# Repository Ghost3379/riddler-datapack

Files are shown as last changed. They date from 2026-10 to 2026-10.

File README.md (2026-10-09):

# Enigma Data Pack - Robin: Origins

A functional custom electronic prop for the indie fan film *"Robin: Origins"*. The design is based on the iconic Enigma Data Packs from the Batman *Arkham* universe, engineered as an interactive gadget that can be carried on set and connected to a PC via USB-C to mount as an encrypted data drive.

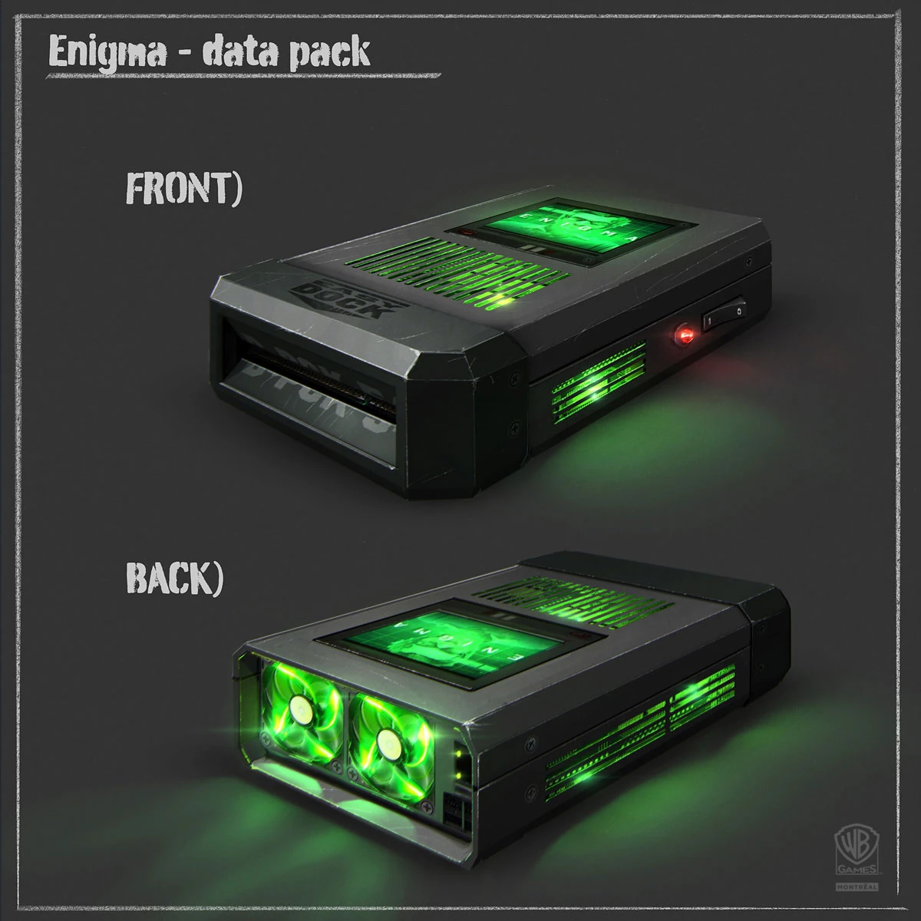
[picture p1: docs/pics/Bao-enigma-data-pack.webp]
Enigma Data Pack Concept


---

## Hardware Versions

The project contains two distinct hardware designs:

1. **Mini Version (Movie Prop - In Production):** An ultra-compact, stunt-safe, pocket-sized tactical drive (~85 × 57 × 12 mm, inspired by rugged portable SSDs like the Samsung T7 Shield). Tailored specifically for the film's action scenes and PC terminal connection.
2. **Full-Size Replica Version:** A heavy, 1:1 scale Arkham military cartridge featuring dual active 40mm cooling fans, internal LiPo battery charging, and full power-rail boost converters.

---

### 1. Mini Version (Movie Hero Prop)
> Located in: [`PCB/Mini Version/Riddler-Datapack mini/`](PCB/Mini%20Version/Riddler-Datapack%20mini/)

Optimized for durability, pocket portability during physical stunt chases, and reliable on-set PC docking:

* **Form Factor:** Compact 60 × 45 mm PCB inside an ~85 × 57 mm enclosure with chamfered `PCIe NVMe` nose cone and front grille vents.
* **Microcontroller:** ESP32-S3-MINI-1 (dual-core, native USB OTG, onboard PCB antenna).
* **Power Architecture:** Purely bus-powered via USB-C (5V VBUS). High-efficiency TLV62568 synchronous step-down buck converter supplies 3.3V @ up to 1A. No internal LiPo batteries required on set, eliminating safety risks and battery downtime.
* **Storage:** MicroSD card socket wired via high-speed **4-bit SDMMC** with hardware pull-ups (4.7kΩ) for fast read/write speeds when mounted as a USB Mass Storage (MSC) drive.
* **Display:** 1.14" IPS TFT LCD (ST7789, 240×135) for crisp "ENIGMA" animations and boot terminals.
* **Illumination:** Integrated addressable RGB LEDs (WS2812B / SK6812) projecting the signature neon green glow through the front casing grille.
* **Protection:** Dedicated USBLC6-2P6 ESD protection on high-speed USB data lines and reverse-polarity Schottky diode on VBUS.

---

### 2. Full-Size Replica Version
> Located in: [`PCB/Riddler-Datapack/`](PCB/Riddler-Datapack/)  
> Full schematic export: [Riddler-Datapack_v0p5.pdf](docs/circuit%20diagrams/Riddler-Datapack_v0p5.pdf)

The full-scale desktop/showcase replica with complete internal subsystem autonomy:

* **Microcontroller:** ESP32-S3-WROOM-1U.
* **Active Cooling:** Dual 40x40mm cooling fans with independent PWM speed control.
* **Power Management:**
  * BQ25170DSGR standalone linear LiPo battery charger (chargeable via USB-C).
  * TPS61023 5V boost converter for fans and high-brightness LED arrays.
  * TLV62568DBV 3.3V buck regulator for MCU logic.
* **Level Shifting:** SN74AHCT125 / 74AHCT1G125 high-speed logic level shifting for 5V LED data lines.
* **Controls:** Physical rocker power switch (`1 / 0`) and dual fan headers.

---

## Visual Reference & In-Game Footage

| Front View (Idle / Off) | Front View (Active "ENIGMA" Display & LEDs) |
| :---: | :---: |
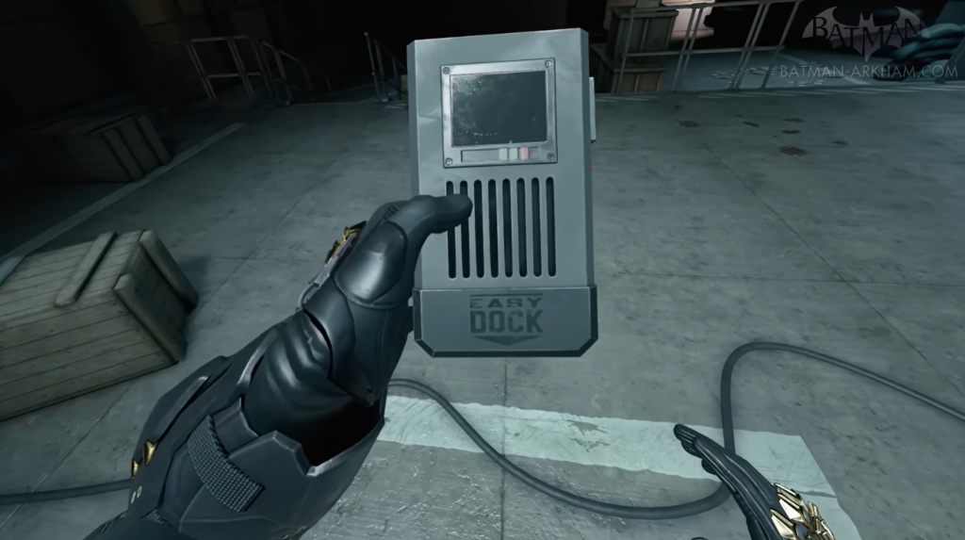
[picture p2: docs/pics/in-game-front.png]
Front View Idle
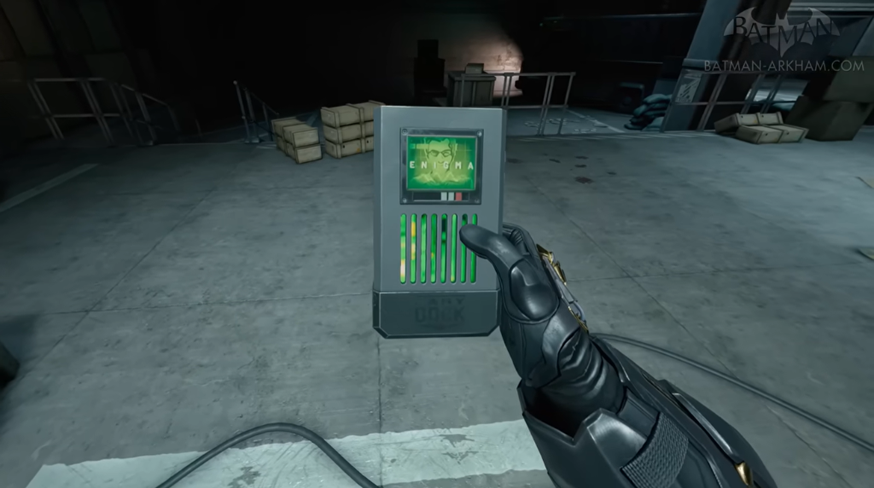
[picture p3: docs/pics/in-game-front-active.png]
Front View Active
|  |  |

| Top Fans & Lighting | Side Controls & Switch | Bottom Dock ("D-PCK 54") |
| :---: | :---: | :---: |
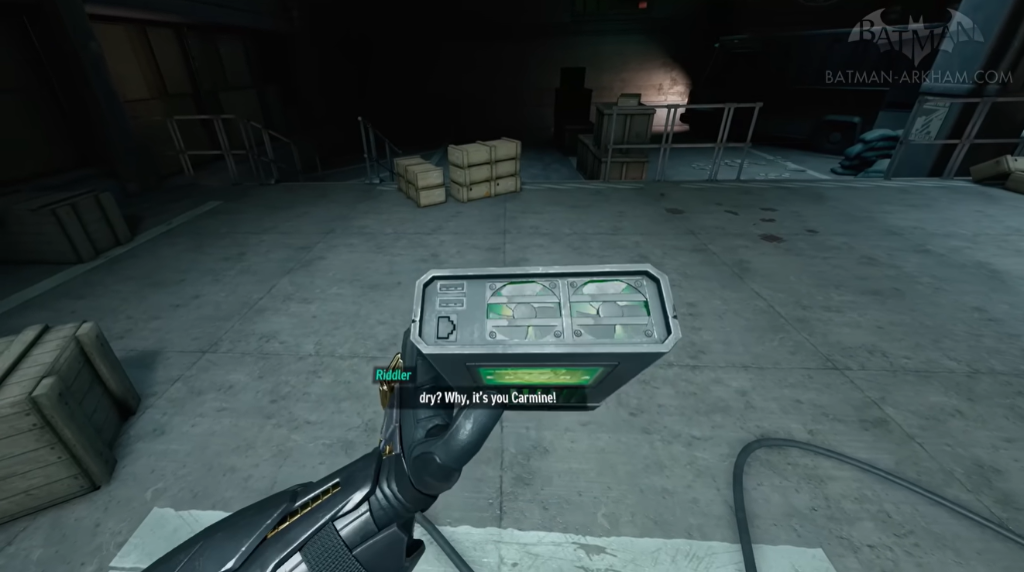
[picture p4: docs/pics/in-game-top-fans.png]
Top View
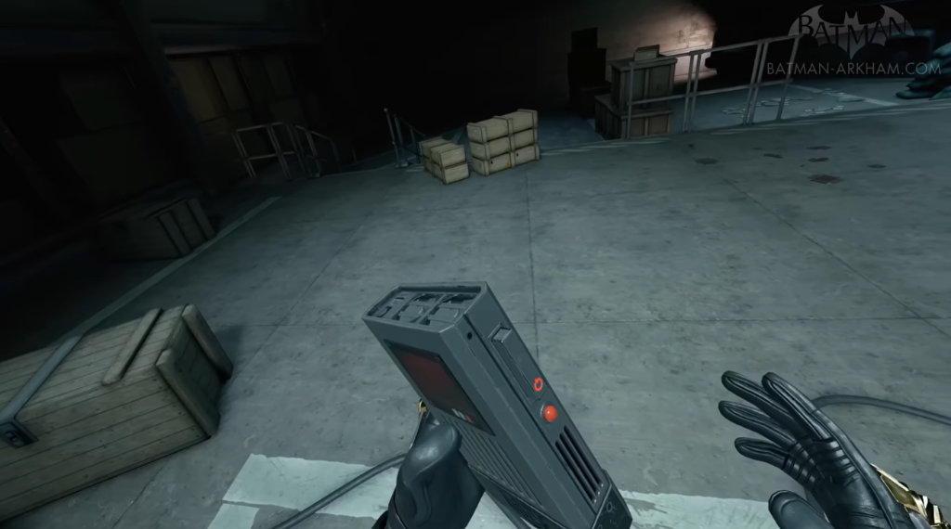
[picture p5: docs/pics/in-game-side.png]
Side View
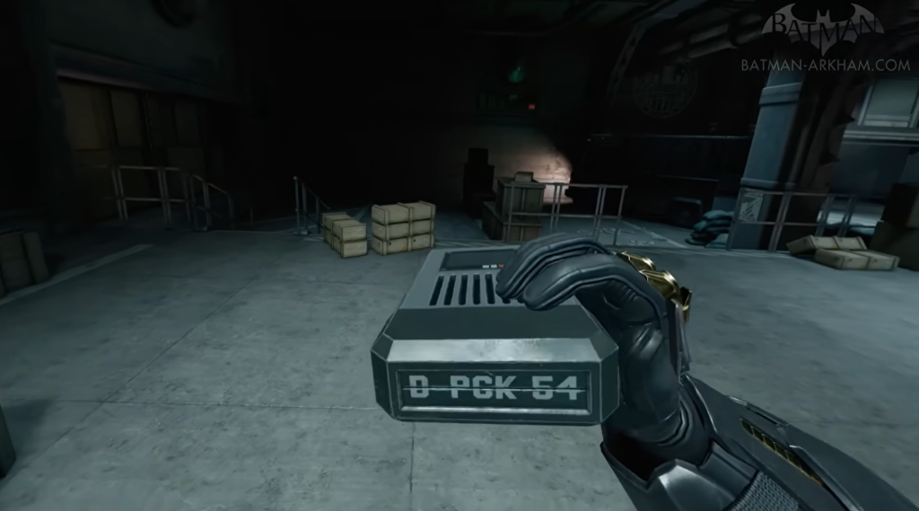
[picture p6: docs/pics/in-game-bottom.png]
Bottom View
|  |  |  |

---

## Sources & Credits

* **Concept Art:** [Arkham City Fandom - Enigma Datapack](https://arkhamcity.fandom.com/wiki/Enigma_Datapack?file=Bao-enigma-data-pack.jpg)
* **Video Game Screenshots & Footage:** [Batman Arkham - Enigma Datapacks Gameplay Footage (YouTube)](https://www.youtube.com/watch?v=1w_udK2QxwU)

---

## License
The software/firmware in the `Firmware` directory is licensed under the GNU General Public License v3.0 (GPLv3).

The hardware design files in the `PCB` directory are licensed under the CERN Open Hardware Licence Version 2 - Strongly Reciprocal (CERN-OHL-S).

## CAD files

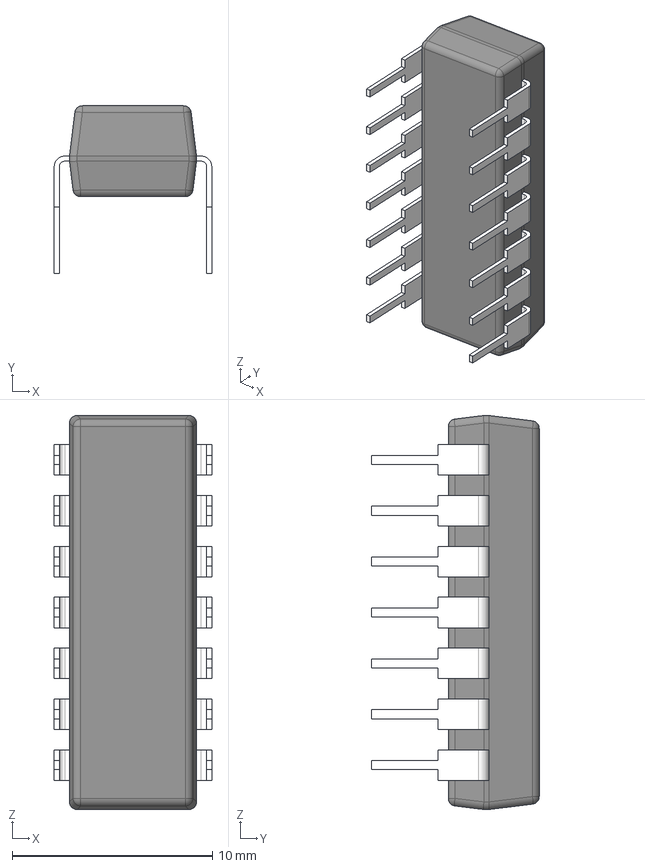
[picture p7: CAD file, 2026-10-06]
PCB/External Footprints&Symbols/3d/N0014A.stp
7.87 x 8.37 x 19.7 mm
BODY_N0014A_AF0
LEAD_N0014A_AF1
LEAD_N0014A x 10
LEAD_N0014A_AF3
LEAD_N0014A_AF0
LEAD_N0014A_AF2

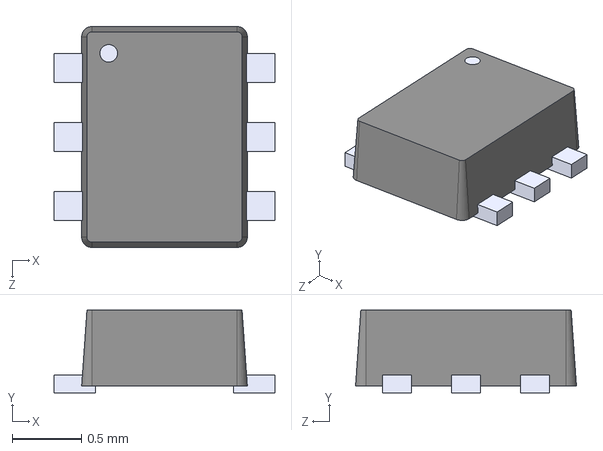
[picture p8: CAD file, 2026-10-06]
PCB/External Footprints&Symbols/3d/TPS61023DRLR.step
1.60 x 0.6 x 1.60 mm

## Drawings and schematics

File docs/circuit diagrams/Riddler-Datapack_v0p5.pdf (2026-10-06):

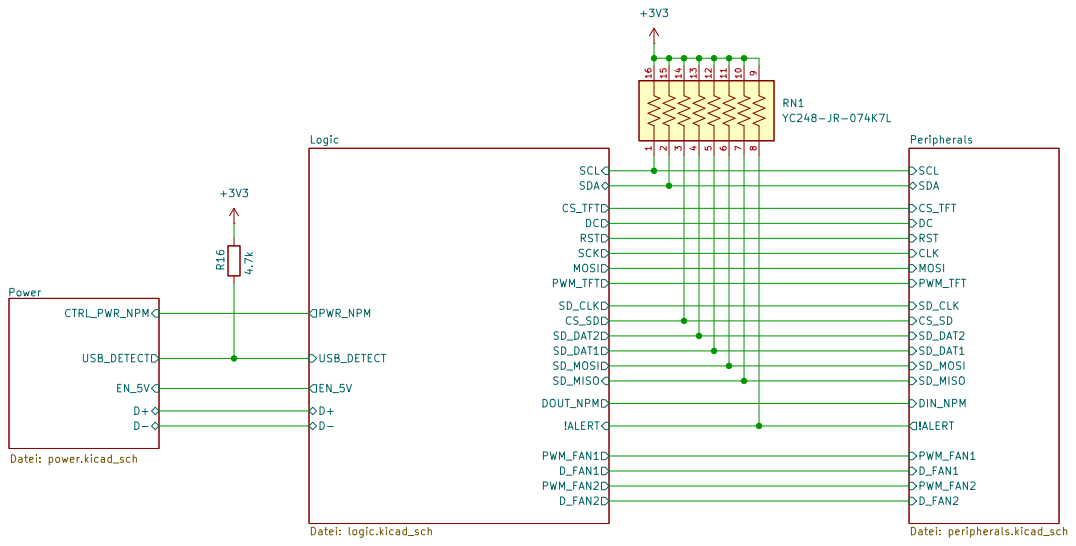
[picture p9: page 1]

D_FAN1 D_FAN2 MOSI PWM_FAN1 PWM_FAN2 PWM_TFT RST SCL SDA SD_DAT2
SD_DAT1 CLK

Size: A4 | Rev:
KiCad E.D.A. 10.0.5 | Id: 1/4

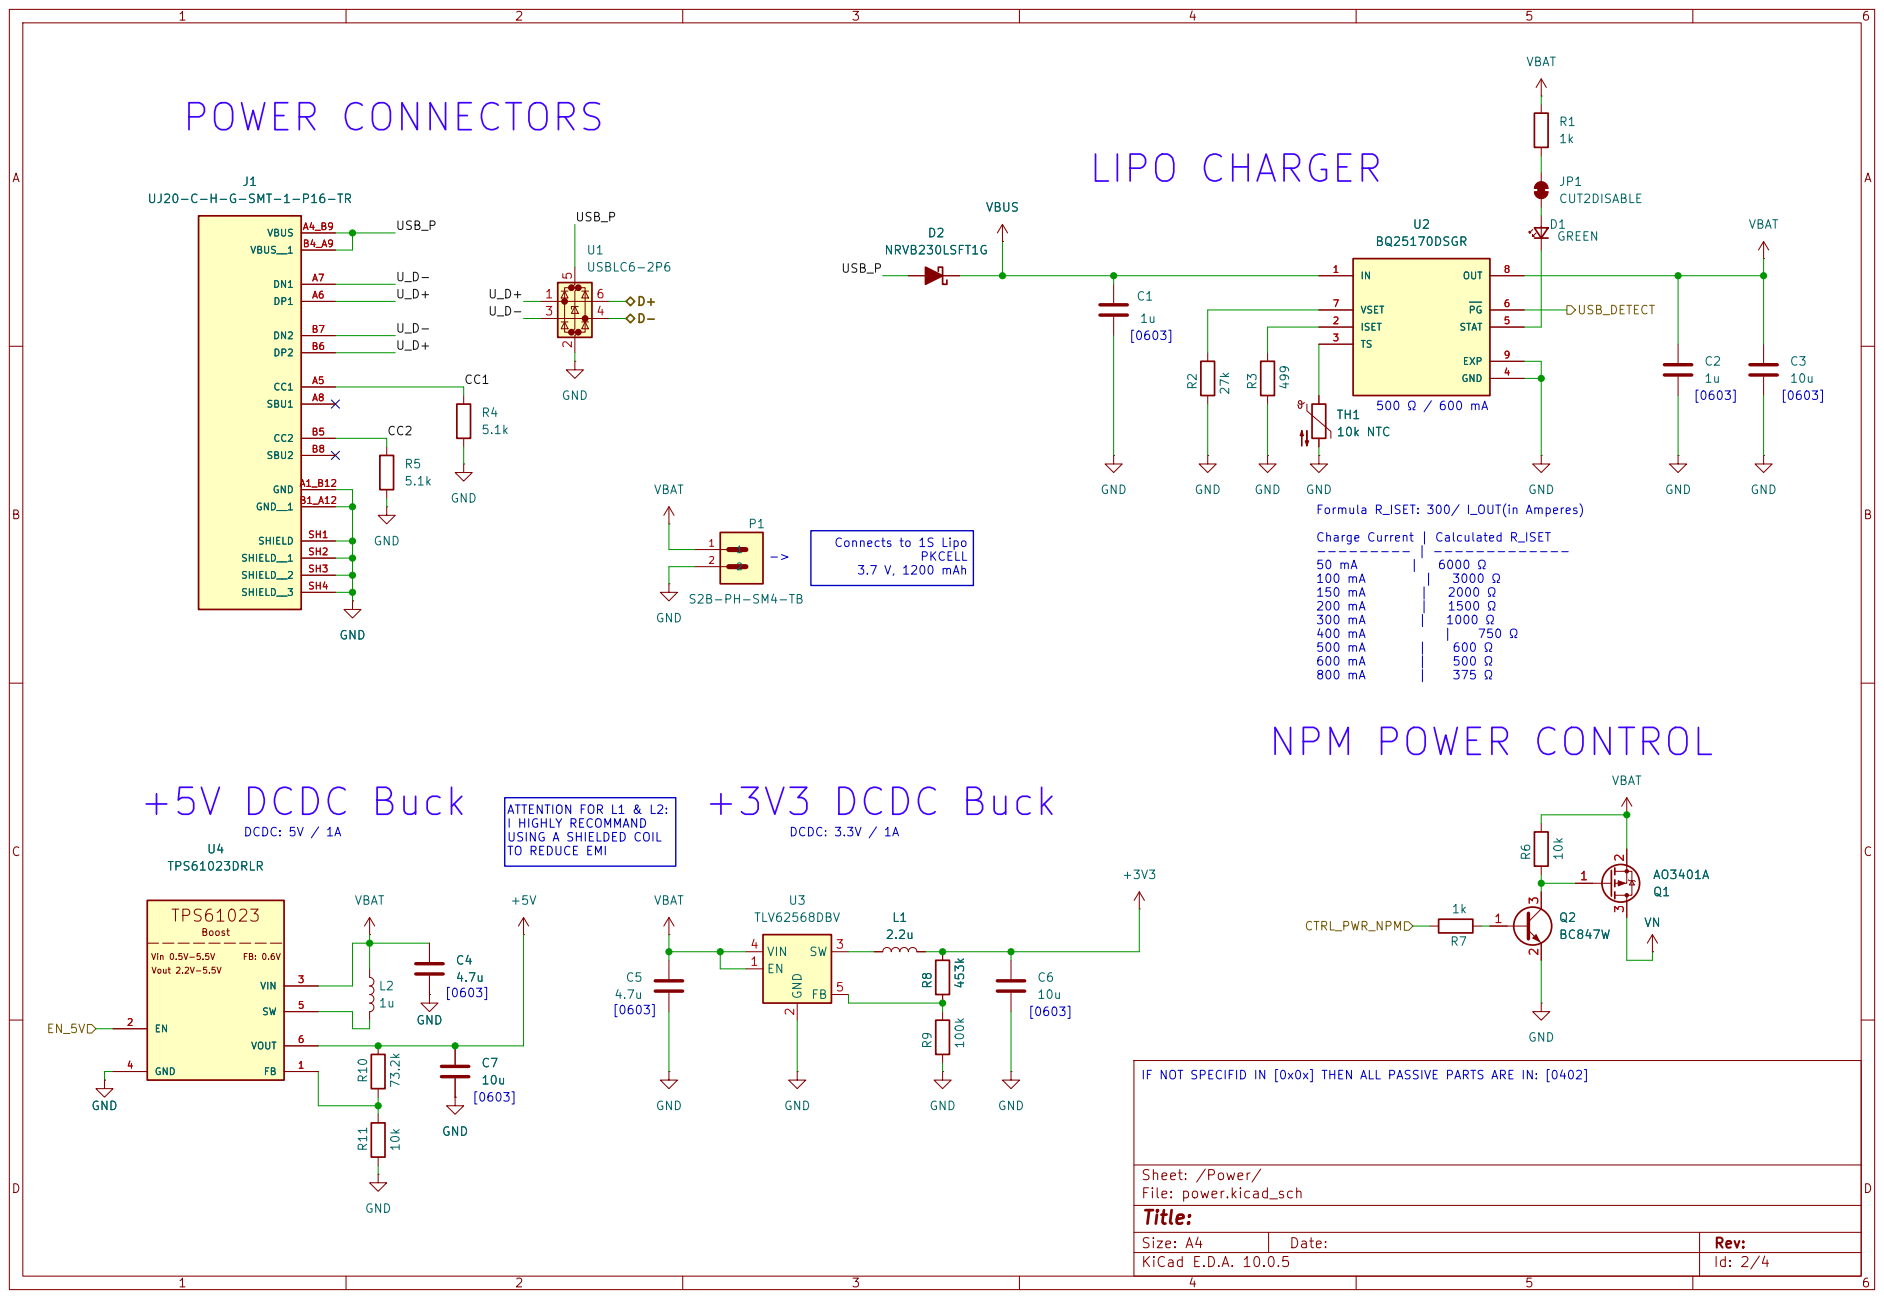
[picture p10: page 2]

ATTENTION FOR L1 & L2:
I HIGHLY RECOMMAND USING A SHIELDED COIL

IF NOT SPECIFID IN [0x0x] THEN ALL PASSIVE PARTS ARE IN: [0402]

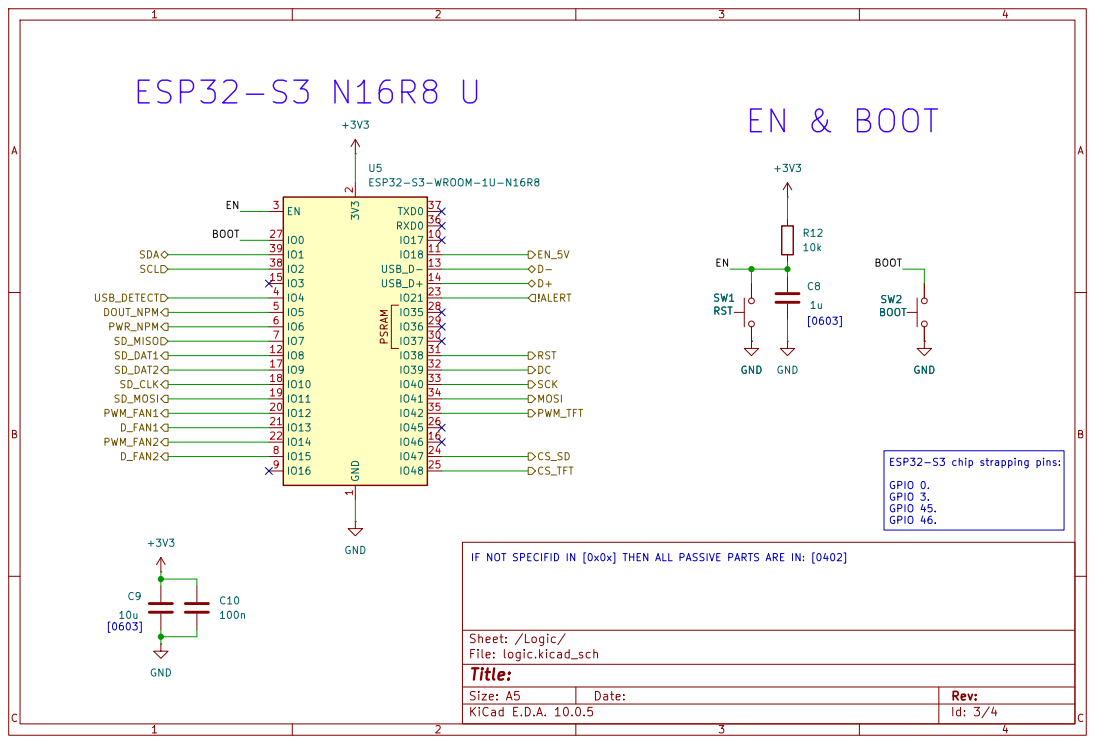
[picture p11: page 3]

[0603] ESP32-S3 chip strapping pins: GPIO 0. GPIO 3. GPIO 45. GPIO 46. SW2 BOOT GND

IF NOT SPECIFID IN [0x0x] THEN ALL PASSIVE PARTS ARE IN: [0402]

Size: A5 | Rev: | C Date:
KiCad E.D.A. 10.0.5 | Id: 3/4

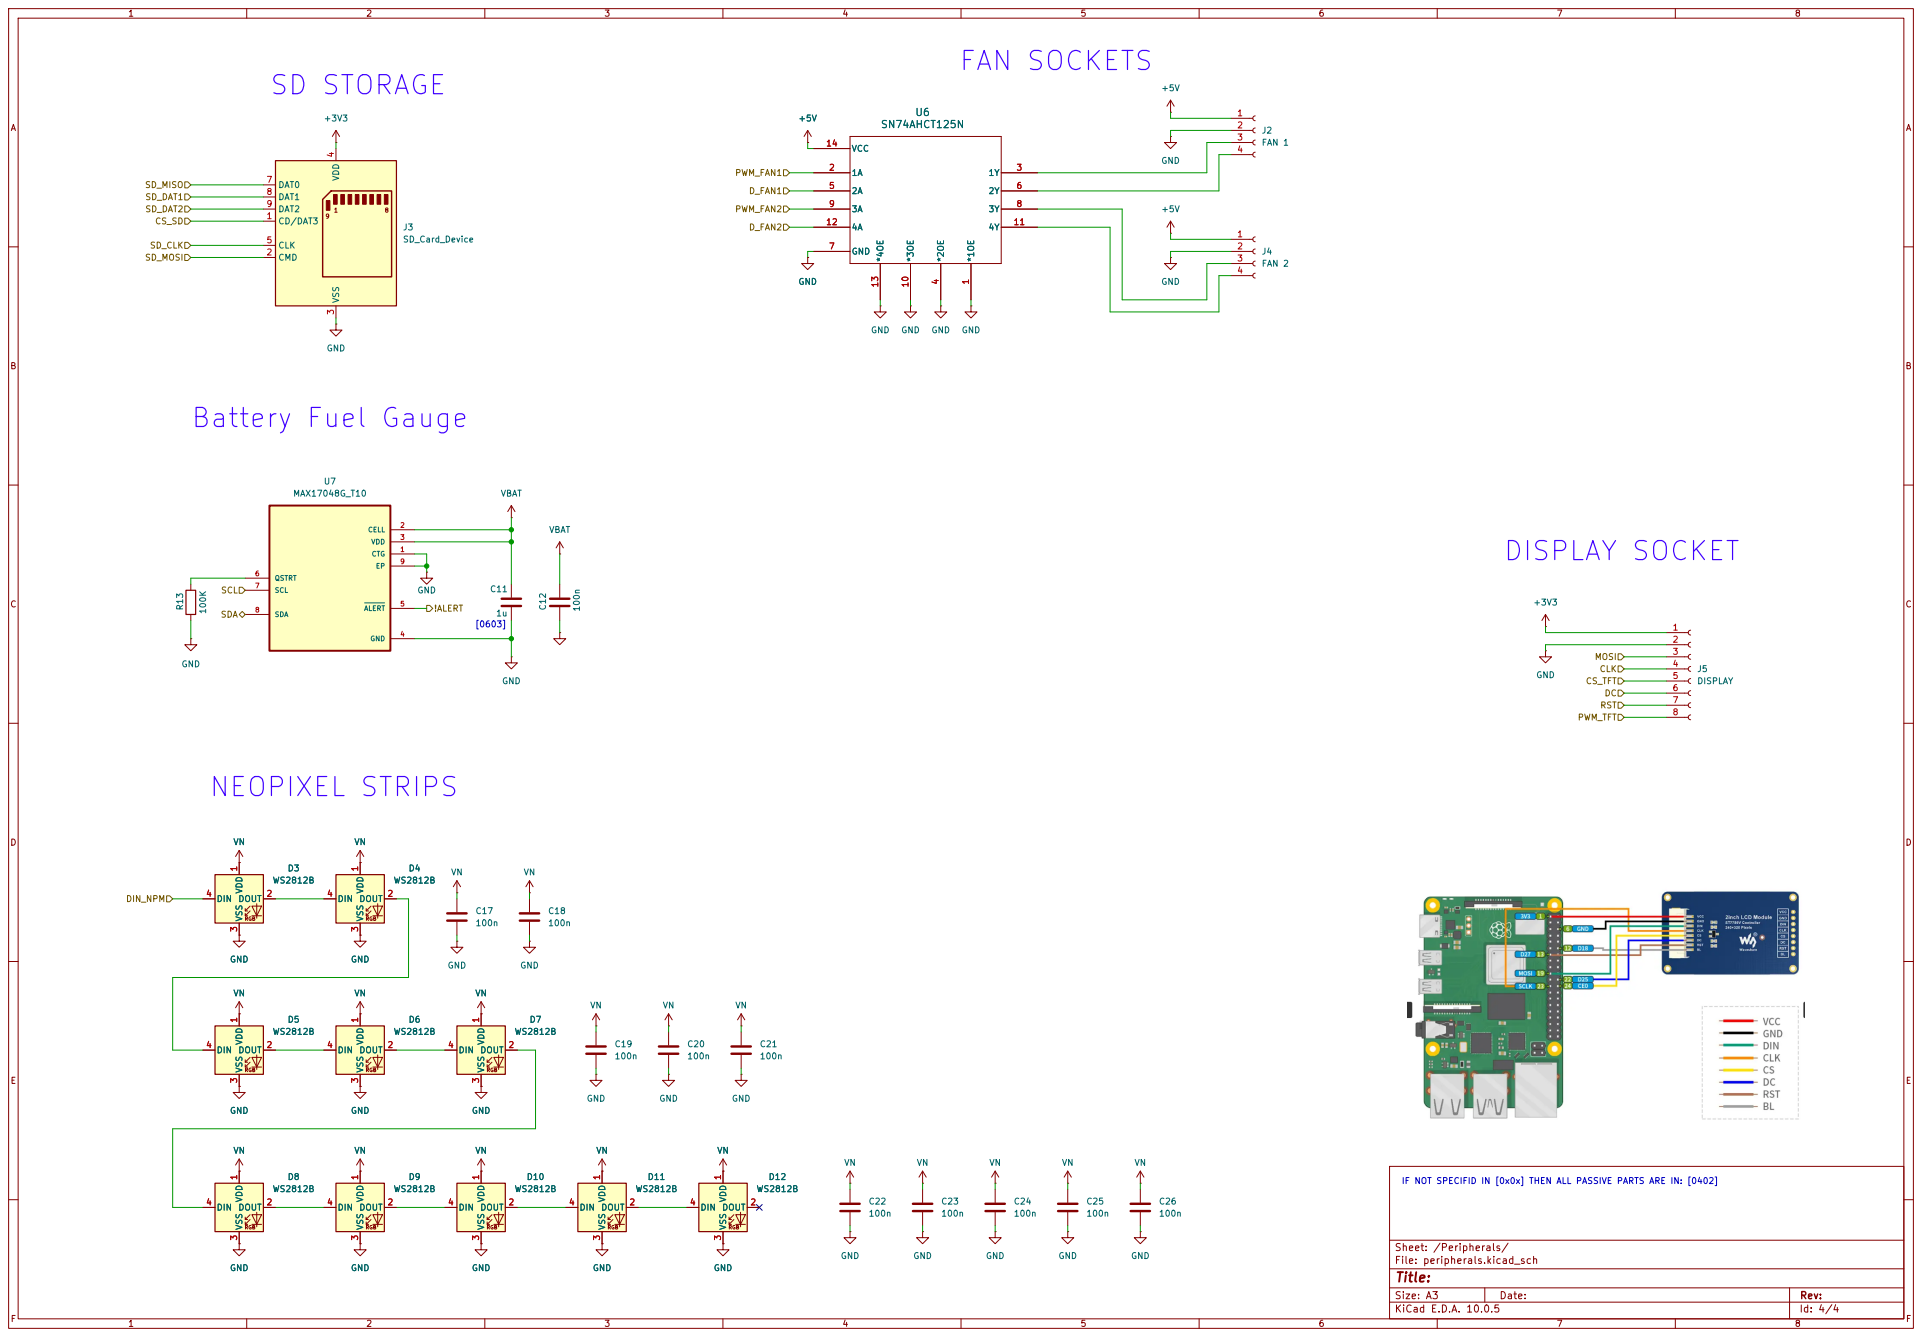
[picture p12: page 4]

IF NOT SPECIFID IN [0x0x] THEN ALL PASSIVE PARTS ARE IN: [0402]

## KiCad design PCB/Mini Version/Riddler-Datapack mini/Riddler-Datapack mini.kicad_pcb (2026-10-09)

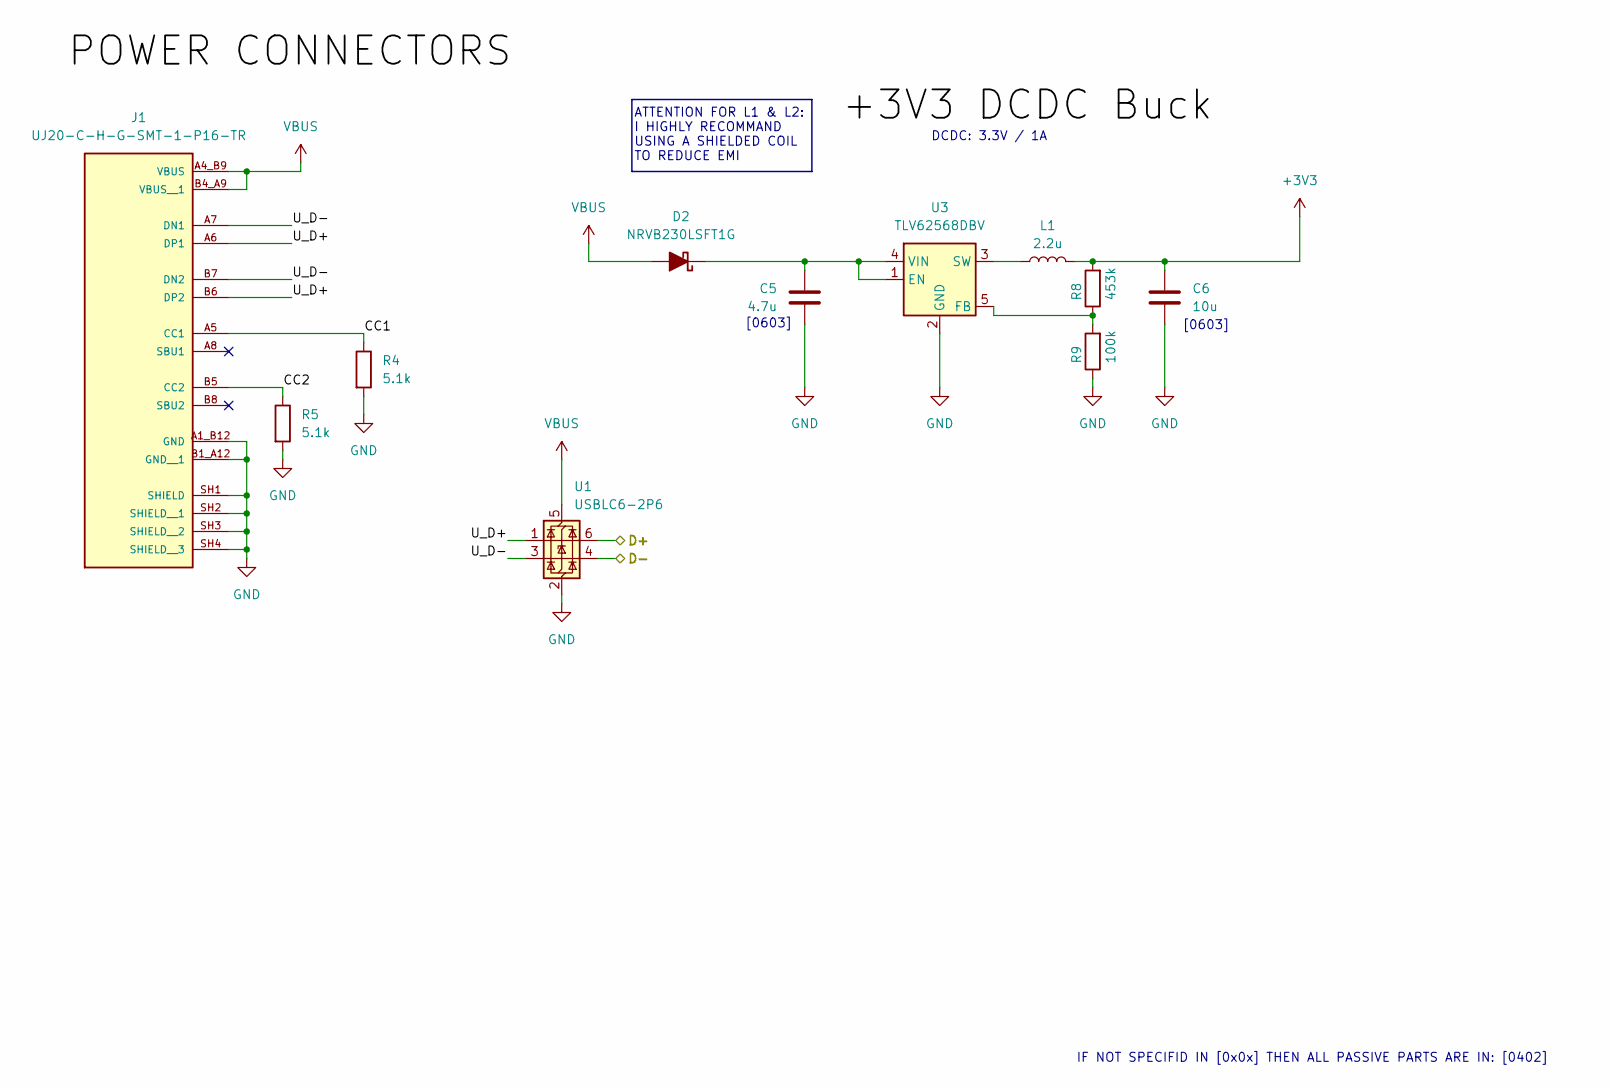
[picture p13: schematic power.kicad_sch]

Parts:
C5: 4.7u; C_0603_1608Metric
C6: 10u; C_0603_1608Metric
D2: NRVB230LSFT1G; D_SOD-123
J1: UJ20-C-H-G-SMT-1-P16-TR; SAMESKY_UJ20-C-H-G-SMT-1-P16-TR; PARTREV 1.0
L1: 2.2u; L_1008_2520Metric; Manufacturer part number SRN2510BTA-2R2M
R4, R5: 5.1k; R_0402_1005Metric
R8: 453k; R_0402_1005Metric
R9: 100k; R_0402_1005Metric
U1: USBLC6-2P6; SOT-666
U3: TLV62568DBV; SOT-23-5

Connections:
+3V3: C6.1, L1.2, R8.2; also elsewhere on the board
/Logic/D+: U1.6 (I/O1); also elsewhere on the board
/Logic/D-: U1.4 (I/O2); also elsewhere on the board
/Power/CC1: J1.A5 (CC1), R4.1
/Power/CC2: J1.B5 (CC2), R5.1
/Power/U_D+: J1.A6 (DP1), J1.B6 (DP2), U1.1 (I/O1)
/Power/U_D-: J1.A7 (DN1), J1.B7 (DN2), U1.3 (I/O2)
GND: C5.2, C6.2, J1.A1_B12 (GND), J1.B1_A12 (GND__1), J1.SH1 (SHIELD), J1.SH2 (SHIELD__1), J1.SH3 (SHIELD__2), J1.SH4 (SHIELD__3), R4.2, R5.2, R9.1, U1.2 (GND), U3.2 (GND); also elsewhere on the board
unnamed: C5.1, D2.1 (K), U3.1 (EN), U3.4 (VIN)
unnamed: R8.1, R9.2, U3.5 (FB)
unnamed: L1.1, U3.3 (SW)
VBUS: D2.2 (A), J1.A4_B9 (VBUS), J1.B4_A9 (VBUS__1), U1.5 (VBUS); also elsewhere on the board

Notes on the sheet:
[0603]
ATTENTION FOR L1 & L2: I HIGHLY RECOMMAND USING A SHIELDED COIL TO REDUCE EMI
DCDC: 3.3V / 1A
IF NOT SPECIFID IN [0x0x] THEN ALL PASSIVE PARTS ARE IN: [0402]

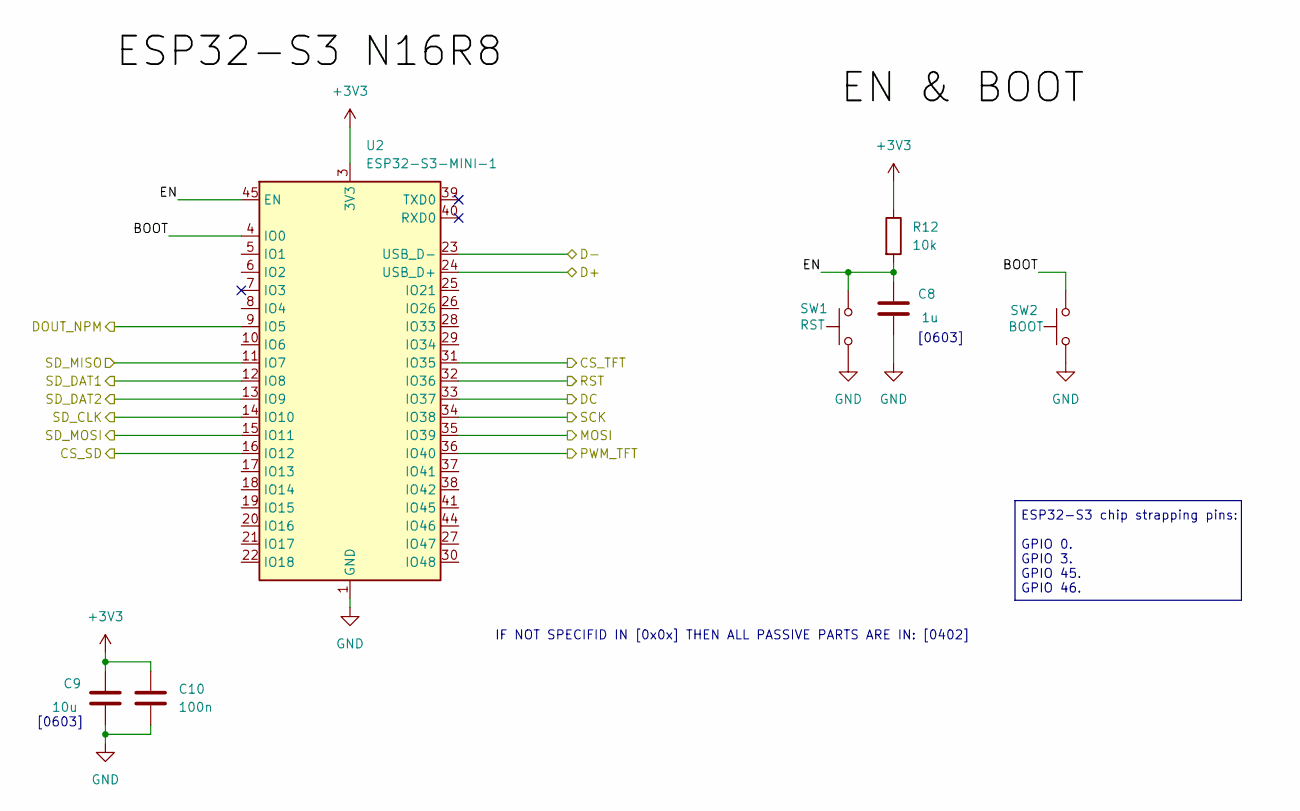
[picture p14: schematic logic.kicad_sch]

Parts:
C8: 1u; C_0603_1608Metric
C9: 10u; C_0603_1608Metric
C10: 100n; C_0402_1005Metric
R12: 10k; R_0402_1005Metric
SW1: RST; SW_Push_1P1T_NO_CK_KMR2
SW2: BOOT; SW_Push_1P1T_NO_CK_KMR2
U2: ESP32-S3-MINI-1; ESP32-S2-MINI-1

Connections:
+3V3: C9.1, C10.1, R12.1, U2.3 (3V3); also elsewhere on the board
/Logic/BOOT: SW2.2, U2.4 (IO0)
/Logic/CS_SD: U2.16 (IO12); also elsewhere on the board
/Logic/CS_TFT: U2.31 (IO35); also elsewhere on the board
/Logic/D+: U2.24 (USB_D+); also elsewhere on the board
/Logic/D-: U2.23 (USB_D-); also elsewhere on the board
/Logic/DC: U2.33 (IO37); also elsewhere on the board
/Logic/DOUT_NPM: U2.9 (IO5); also elsewhere on the board
/Logic/EN: C8.1, R12.2, SW1.2, U2.45 (EN)
/Logic/MOSI: U2.35 (IO39); also elsewhere on the board
/Logic/PWM_TFT: U2.36 (IO40); also elsewhere on the board
/Logic/RST: U2.32 (IO36); also elsewhere on the board
/Logic/SCK: U2.34 (IO38); also elsewhere on the board
/Logic/SD_CLK: U2.14 (IO10); also elsewhere on the board
/Logic/SD_DAT1: U2.12 (IO8); also elsewhere on the board
/Logic/SD_DAT2: U2.13 (IO9); also elsewhere on the board
/Logic/SD_MISO: U2.11 (IO7); also elsewhere on the board
/Logic/SD_MOSI: U2.15 (IO11); also elsewhere on the board
GND: C8.2, C9.2, C10.2, SW1.1, SW2.1, U2.1 (GND), U2.2 (GND), U2.42 (GND), U2.43 (GND), U2.46 (GND), U2.47 (GND), U2.48 (GND), U2.49 (GND), U2.50 (GND), U2.51 (GND), U2.52 (GND), U2.53 (GND), U2.54 (GND), U2.55 (GND), U2.56 (GND), U2.57 (GND), U2.58 (GND), U2.59 (GND), U2.60 (GND), U2.61 (GND), U2.62 (GND), U2.63 (GND), U2.64 (GND), U2.65 (GND); also elsewhere on the board

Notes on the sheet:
IF NOT SPECIFID IN [0x0x] THEN ALL PASSIVE PARTS ARE IN: [0402]
ESP32-S3 chip strapping pins: GPIO 0. GPIO 3. GPIO 45. GPIO 46.
[0603]

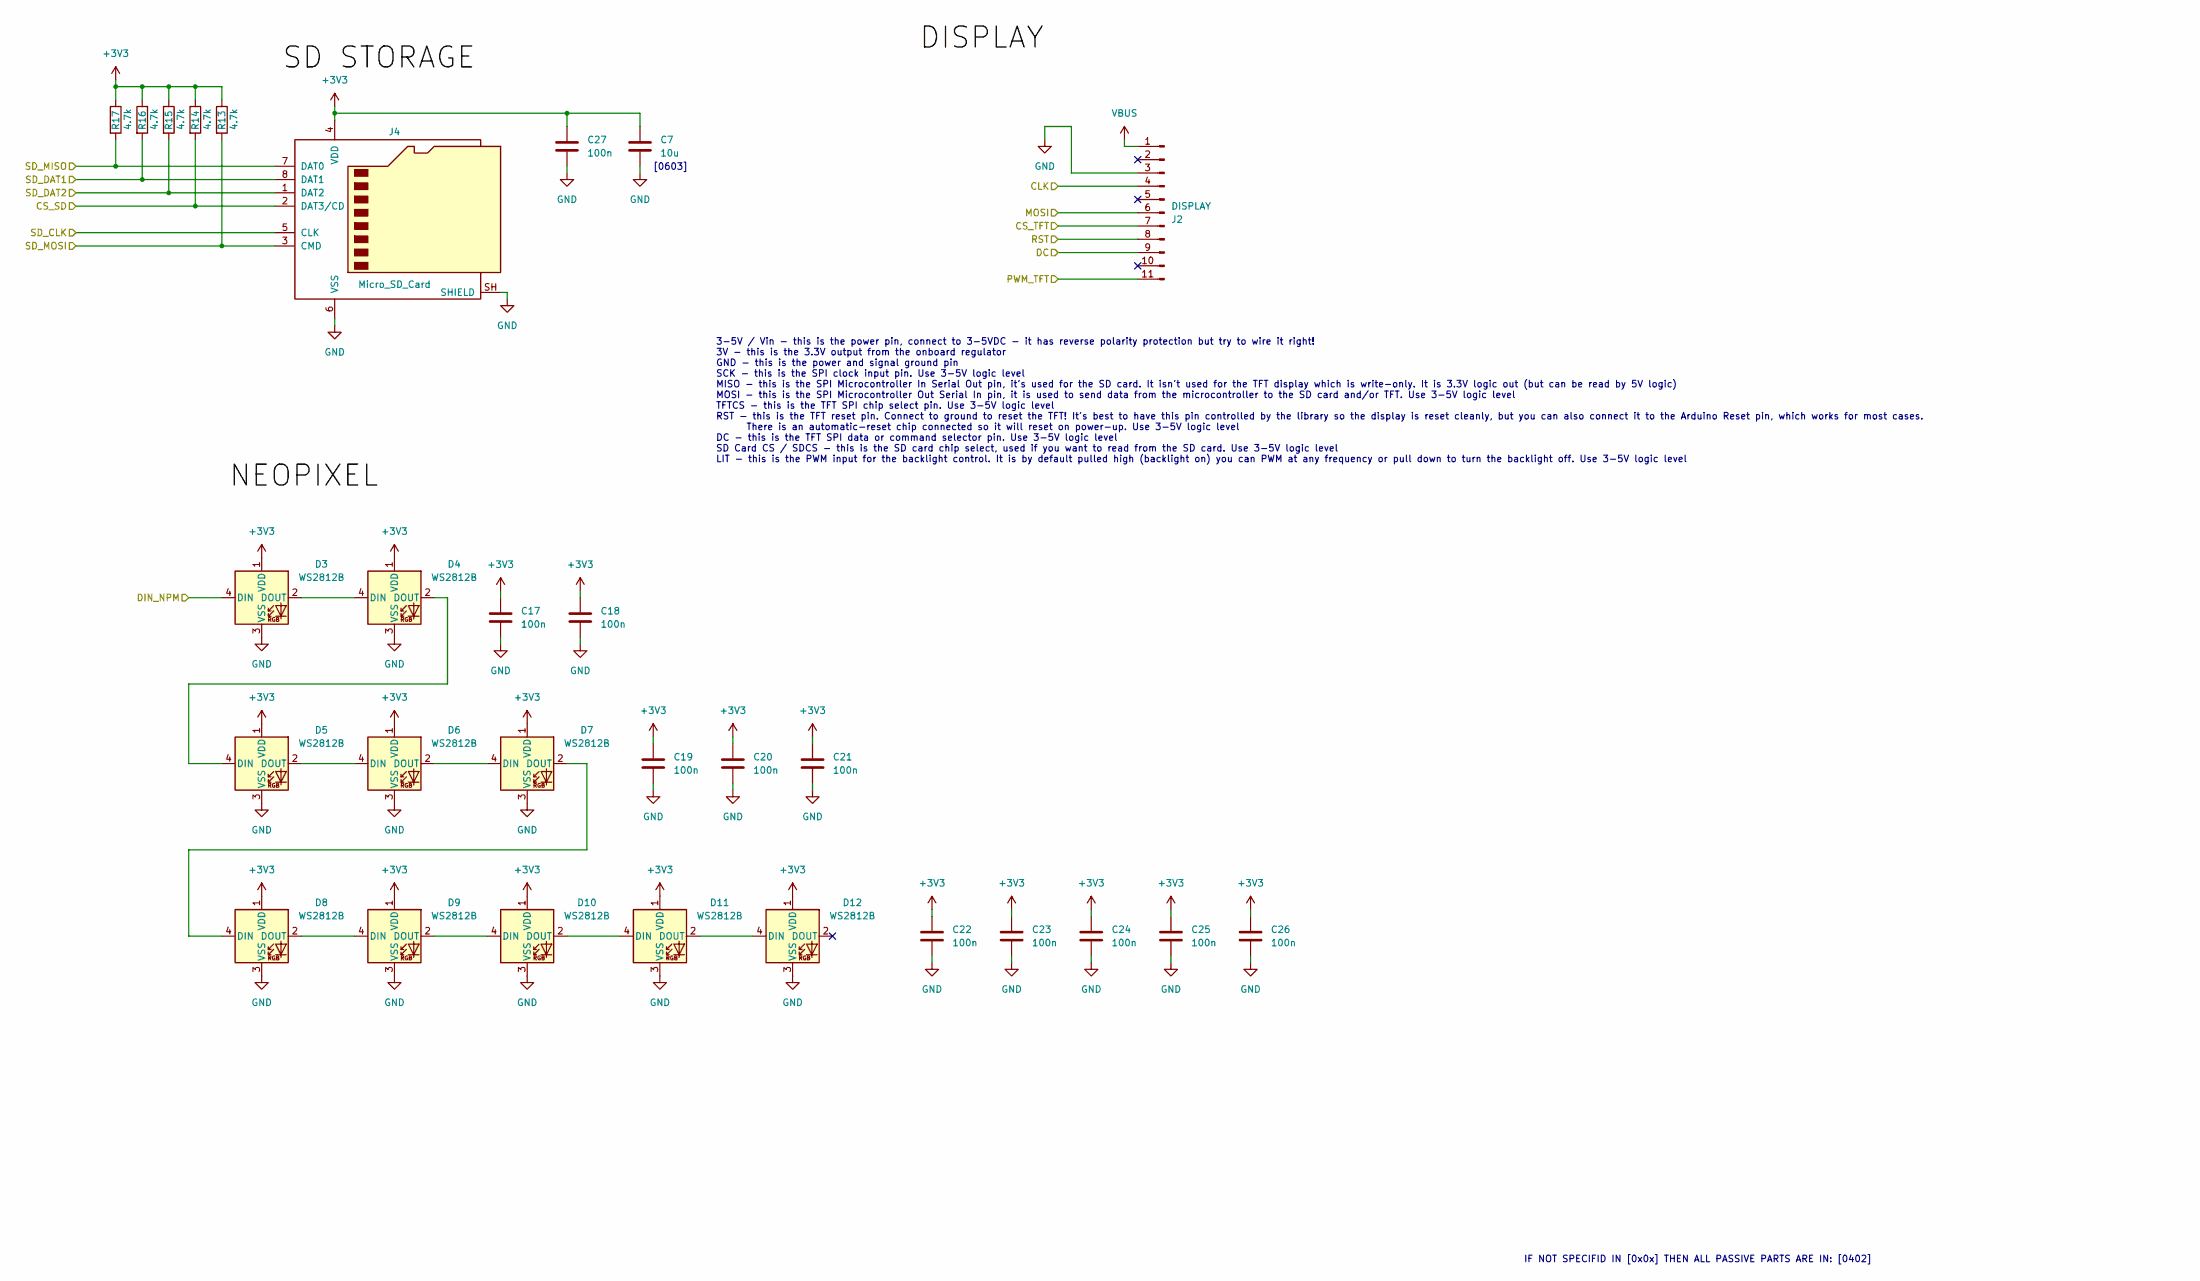
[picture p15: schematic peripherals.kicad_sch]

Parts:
C7: 10u; C_0603_1608Metric
C17, C18, C19, C20, C21, C22, C23, C24, C25, C26, C27: 100n; C_0402_1005Metric
D3, D4, D5, D6, D7, D8, D9, D10, D11, D12: WS2812B; LED_WS2812B_PLCC4_5.0x5.0mm_P3.2mm
J2: DISPLAY; PinHeader_1x11_P2.54mm_Vertical
J4: Micro_SD_Card; microSD_HC_Wuerth_693072010801
R13, R14, R15, R16, R17: 4.7k; R_0402_1005Metric

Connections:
+3V3: C7.1, C17.1, C18.1, C19.1, C20.1, C21.1, C22.1, C23.1, C24.1, C25.1, C26.1, C27.1, D3.1 (VDD), D4.1 (VDD), D5.1 (VDD), D6.1 (VDD), D7.1 (VDD), D8.1 (VDD), D9.1 (VDD), D10.1 (VDD), D11.1 (VDD), D12.1 (VDD), J4.4 (VDD), R13.1, R14.1, R15.1, R16.1, R17.1; also elsewhere on the board
/Logic/CS_SD: J4.2 (DAT3/CD), R14.2; also elsewhere on the board
/Logic/CS_TFT: J2.7; also elsewhere on the board
/Logic/DC: J2.9; also elsewhere on the board
/Logic/DOUT_NPM: D3.4 (DIN); also elsewhere on the board
/Logic/MOSI: J2.6; also elsewhere on the board
/Logic/PWM_TFT: J2.11; also elsewhere on the board
/Logic/RST: J2.8; also elsewhere on the board
/Logic/SCK: J2.4; also elsewhere on the board
/Logic/SD_CLK: J4.5 (CLK); also elsewhere on the board
/Logic/SD_DAT1: J4.8 (DAT1), R16.2; also elsewhere on the board
/Logic/SD_DAT2: J4.1 (DAT2), R15.2; also elsewhere on the board
/Logic/SD_MISO: J4.7 (DAT0), R17.2; also elsewhere on the board
/Logic/SD_MOSI: J4.3 (CMD), R13.2; also elsewhere on the board
GND: C7.2, C17.2, C18.2, C19.2, C20.2, C21.2, C22.2, C23.2, C24.2, C25.2, C26.2, C27.2, D3.3 (VSS), D4.3 (VSS), D5.3 (VSS), D6.3 (VSS), D7.3 (VSS), D8.3 (VSS), D9.3 (VSS), D10.3 (VSS), D11.3 (VSS), D12.3 (VSS), J2.3, J4.6 (VSS), J4.SH (SHIELD); also elsewhere on the board
unnamed: D3.2 (DOUT), D4.4 (DIN)
unnamed: D4.2 (DOUT), D5.4 (DIN)
unnamed: D5.2 (DOUT), D6.4 (DIN)
unnamed: D6.2 (DOUT), D7.4 (DIN)
unnamed: D7.2 (DOUT), D8.4 (DIN)
unnamed: D8.2 (DOUT), D9.4 (DIN)
unnamed: D9.2 (DOUT), D10.4 (DIN)
unnamed: D10.2 (DOUT), D11.4 (DIN)
unnamed: D11.2 (DOUT), D12.4 (DIN)
VBUS: J2.1; also elsewhere on the board

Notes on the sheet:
IF NOT SPECIFID IN [0x0x] THEN ALL PASSIVE PARTS ARE IN: [0402]
[0603]
3-5V / Vin - this is the power pin, connect to 3-5VDC - it has reverse polarity protection but try to wire it right! 3V - this is the 3.3V output from the onboard regulator GND - this is the power and signal ground pin SCK - this is the SPI clock input pin. Use 3-5V logic level MISO - this is the S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

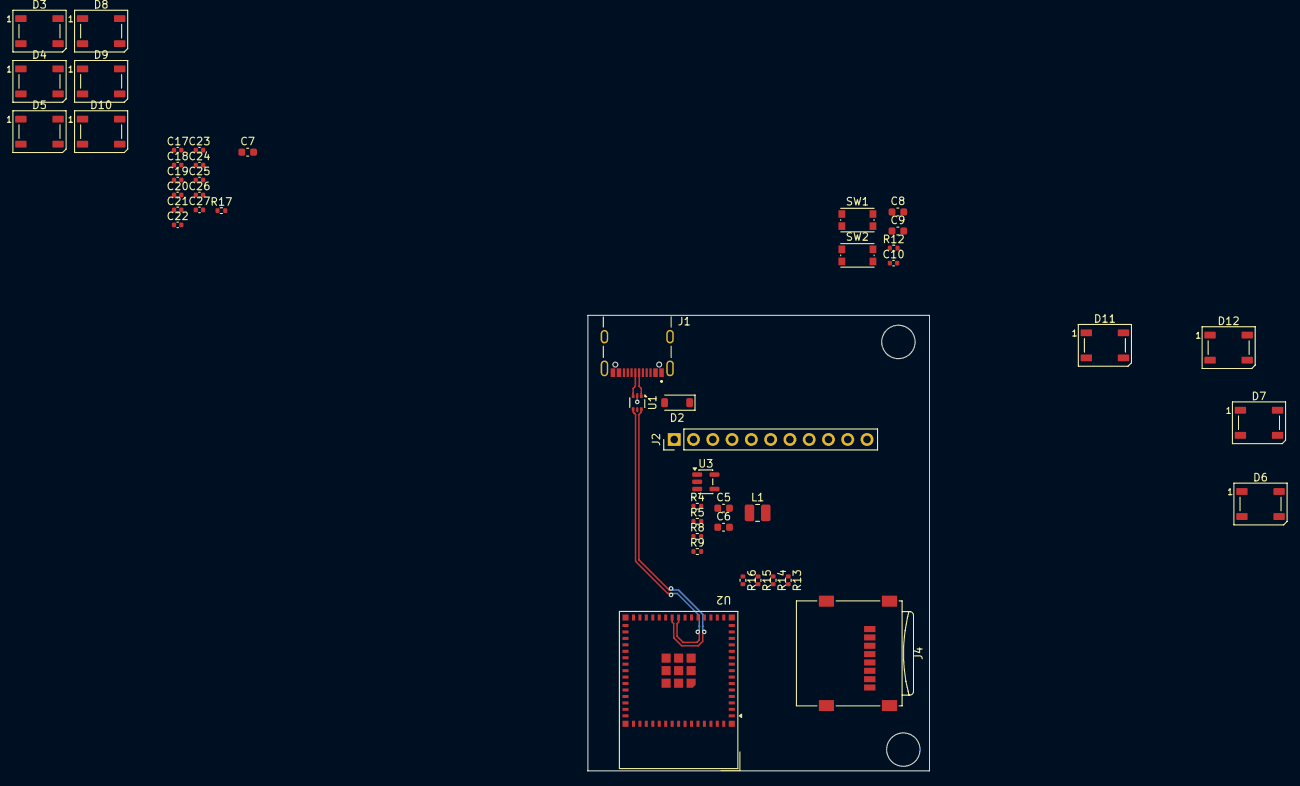
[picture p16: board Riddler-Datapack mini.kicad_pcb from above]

Board: 4 copper layers, 45.0 x 60.0 mm, 47 parts (0 on the bottom side), 36 nets.

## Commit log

2026-10-06 Complete schematics v0.5, add schematic PDF export and active prop reference
    [Riddler-Datapack.kicad_sch, logic.kicad_sch, peripherals.kicad_sch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]
2026-10-09 feat(hardware): add Mini Datapack movie prop edition and update README
    [Riddler-Datapack mini.kicad_pcb, Riddler-Datapack mini.kicad_sch, logic.kicad_sch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]
2026-10-14 feat(hardware): complete 4-layer PCB routing for Mini Datapack prop and add 3D exports
2026-10-15 Minor updates including: silkscreen design, and changed out the button
2026-10-15 updated usbc location, added more relief vias to vbus and gnd
2026-10-19 production stuff and riddle me this text on pcb
2026-10-20 chore(assets): add Riddler font zip archive for silkscreen text
2026-10-20 feat(mini): release v1.2 - green solder mask, silkscreen polish, and JLCPCB production files
2026-10-26 feat(firmware): add initial ESP32-S3 firmware with TinyUSB MSC, LovyanGFX display, and FastLED engines
2026-10-27 docs(pcb): add Interactive HTML BOM (ibom.html) for Mini Datapack assembly
2026-10-27 fix(firmware): invert display rotation 180 deg and set LED color order to BRG for green
2026-10-28 feat(firmware): switch to Adafruit_NeoPixel with pure green and 15% cinematic brightness
